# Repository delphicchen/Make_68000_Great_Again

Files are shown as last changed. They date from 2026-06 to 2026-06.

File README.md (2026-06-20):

# 68k nano — PGA-68 / 4-layer edition

A hardware fork of **[68k nano](https://github.com/74hc595/68k-nano)**, Matt
Sarnoff's minimal single-board Motorola 68000 computer, **adapted to use a
PGA-68 packaged CPU (MC68HC000RC) instead of the original DIP-64**, and
re-laid-out on a **4-layer** board.

The electrical design — the memory map, glue logic, RAM/ROM/UART, the ROM
firmware, and all software — is Matt Sarnoff's original work, used here under the
BSD-3-Clause license (see below). **This fork only changes the CPU package and the
physical board layout; the schematic netlist is unchanged.**

> ⚠️ This is an unofficial derivative and is **not affiliated with, nor endorsed
> by, the original author.**

---

## What this fork changes

- **CPU package: DIP-64 → PGA-68.** New footprint `PadRows:MC68HC000_PGA68` whose
  **pad numbers equal the DIP-64 pin numbers**, so the existing `CPU_NXP_68000`
  schematic symbol and the entire netlist are reused unchanged.
- **4-layer stackup.** A PGA's inner pins cannot "escape" on two layers, so the
  board is now: `F.Cu` / `B.Cu` signal, **`In1.Cu` = GND plane, `In2.Cu` = VCC
  plane**.
- **Re-laid-out and re-routed.** Main components repositioned to clear the PGA;
  the board is fully auto-routed from the command line (FreeRouting headless) with
  a small custom maze router closing any nets FreeRouting leaves. Result:
  **0 unconnected, 0 copper/clearance DRC violations.**
- **Verified pin-by-pin.** Every pad was checked two ways — (1) it carries the
  same net as the original DIP board, and (2) its physical grid location matches
  the Motorola M68000 datasheet PGA pinout (Fig 11-2). See `PGA68/verify_pins.py`.

## This fork's additions — see [`PGA68/`](PGA68/)

> The notes in `PGA68/` are written in 中文 (Traditional Chinese).

| File | What it is |
|---|---|
| `pin_mapping_DIP64_to_PGA68.md` | DIP-64 ↔ PGA-68 pin map + datasheet bottom-view chart |
| `verify_pins.py` | Pin-by-pin verification (netlist + datasheet placement) |
| `4層佈線完成報告.md` | Routing completion report (layers, DRC, file list) |
| `convert_4layer.py`, `import_ses_4l.py`, `add_pours.py`, `maze_route_6.py`, `rebuild_pga_pcb.py` | The conversion / routing scripts |
| `顯示器擴充指南.md` | Adding a display (ESP32/FabGL serial terminal, or a bus video card) |
| `設計隨筆.md` | Design notes (compute-power irony, "smart peripheral" philosophy) |

Board files:

- **`68000sbc.kicad_pcb`** — the board, opens by default with the
  `68000sbc.kicad_pro` project. 4-layer layout with components re-placed and the
  board fully re-routed; DRC-clean (0 unconnected, 0 copper/clearance violations).
- `68000sbc_v1.kicad_pcb` — the earlier layout, kept for reference (open directly
  in the PCB editor).
- `68000sbc.sch` (schematic, shared), and the footprint
  `PadRows.pretty/MC68HC000_PGA68.kicad_mod`.

A reusable, board-agnostic version of the headless routing workflow also exists as
a Claude Code skill (`kicad-autoroute`); it is not part of this repo.

---

## The original design & full documentation

**Everything about how the computer actually works** — features, the memory map,
the bill of materials, how to build it, and the ROM firmware (boot process,
interactive command shell, serial loader, debugger, system-call API) — is from the
original project and is preserved unchanged here as
**[`README.original.md`](README.original.md)** (and `API.md`, `bom.txt`, `code/`).

- **Original project:** *68k nano* by **Matt Sarnoff** — <https://github.com/74hc595/68k-nano>
- <https://msarnoff.org> · [@txsector](https://twitter.com/txsector)

If you want to actually build and run this, **read `README.original.md` first** —
the part counts, firmware, and usage are all there. This PGA-68 board needs the
same BOM, just with a PGA-socketed `MC68HC000RC` in place of the DIP-64 CPU. A full
English purchasing list for *this* board — generated from the actual footprints,
with sockets, the 4-layer PCB spec, and build notes — is in **[`BOM.md`](BOM.md)**.

## License

BSD 3-Clause License — Copyright (c) 2020 Matt Sarnoff. See [`LICENSE`](LICENSE).

The PGA-68 conversion work added in this fork (the footprint, the `PGA68/` scripts
and notes, and the board re-layout) is contributed under the same BSD-3-Clause
terms.

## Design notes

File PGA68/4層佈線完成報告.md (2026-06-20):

# 68k-nano PGA-68 — 4 層板佈線完成報告（2026-06-14）

---

## 更新（2026-06-20）：目前定案檔為 v2,腳位已對 datasheet 逐格核實 ✅

**目前 active／定案檔 = `68k-nano/68000sbc.kicad_pcb`（v2,使用者重新擺位後重佈線版）。**
本報告下方原始數據為 v1;v2 走線更精簡。板外框 **127.0 × 97.25 mm**。

| 項目 | v1（舊） | v2（目前 active） |
|---|---|---|
| 走線段 | 2540 | **1964** |
| via | 200 | **96** |
| 鋪銅區 | 4 | 4 |
| 層數 | 4 | 4（F 信號／In1 GND／In2 VCC／B 信號）|

### 腳位映射完整驗證鏈（每段獨立核過,無斷點）
1. **datasheet Fig 11-2（底視圖）→ 對照表 ASCII grid**：10×10 逐格相符,4 個 NC（A1／J4／K1／K10）位置一致
2. **對照表 → footprint pad (x,y)**：68/68 pad 全數手動核對;底視圖→頂視圖**左右鏡像**方向正確（col1→+x、rowA→+y,pin-1 A1 落在 (11.43, 11.43)）
3. **footprint pad 號 = DIP 腳號 → 原理圖網路**：相容 `CPU_NXP_68000` 符號
4. **DIP 腳號 → 信號**：標準 68000 DIP-64 腳位

→ 結論：真實 **MC68HC000RC** 晶片插入後,每根針都落在帶有正確網路的孔位。網表與原始 DIP 板逐點等價。

### v2 DRC（kicad-cli 9.0.2,2026-06-20）
- **0 未連接焊盤、0 短路、0 間距違規、0 footprint 錯誤**
- 14 條非電氣違規（**不阻斷打板**）：
  - `courtyards_overlap` ×10：去耦電容／排阻貼著各自 IC 擺（外觀／機械,通常可接受）
  - `solder_mask_bridge` ×4：連接器 **J1** 相鄰不同網路焊盤的綠漆橋寬 < 0.25mm（組裝時注意吃錫橋,非銅短路）

### 採購清單
- 英文版見 [`../BOM.md`](../BOM.md)（repo 內,依 v2 實際 footprint 產生,含驗證摘要）

---

## 結論：佈線 100% 完成 ✅

DIP-64 主板成功改造為 **PGA-68 / 4 層板**並完成全部佈線：
- **未連接：0**（全部網路接通）
- **電氣/銅箔 DRC 違規：0**（無短路、無間距違規、無懸空走線、無孔距違規）
- 走線 2540 段、via 200 個、4 個鋪銅區
- 剩 184 條 DRC 為外觀/程式庫類（文字大小、絲印、footprint 與庫差異），與原始上游板同類，**非打板阻斷項**

## 流程

1. **DIP-64 → PGA-68**：footprint pad 號 = DIP 腳號（相容原符號），中心 (63.5, 45.72)
2. **避讓搬移**：X1/X2 振盪器 → (72.39, 76.2)；J5/J6 排針 → 頂邊條帶 (y 34.29)；板頂邊上移 6.4mm
3. **改 4 層板**（PGA 內圈腳在 2 層板無法逃線）：
   - F.Cu(信號) / In1.Cu(GND 實心平面) / In2.Cu(VCC 實心平面) / B.Cu(信號)
4. **FreeRouting 自動佈線**（4 層全信號層）：137 條 → 完成 119（87%）
5. **加內層電源平面**：In1=GND、In2=VCC，pad 連接設 FULL（實心）
6. **自製迷宮繞線器**接完剩下 6 條（FreeRouting 卡住的跨板長走線）：
   - 0.1mm 格、Lee/Dijkstra、4 鄰（直角）、via 用獨立放置網格做間距檢查
   - `/A22 /~RDU /A5 /A13 /A1 /A4` 全部接通，DRC 零電氣違規

## 層疊（送嘉立創需指定 4 層）

| 層 | 用途 |
|----|---|
| F.Cu（頂） | 信號 |
| In1.Cu | GND 實心平面 |
| In2.Cu | VCC 實心平面 |
| B.Cu（底） | 信號 |

## 檔案

- `68k-nano/68000sbc.kicad_pcb` — **最終檔（4 層、100% 佈線、DRC 電氣零違規）**
- `68k-nano/68000sbc.kicad_pcb.backup_fully_routed` — 完成版備份
- `68k-nano/68000sbc.kicad_pcb.backup_before_maze` — 接最後 6 條前（FreeRouting 完成 119 條）
- `68k-nano/68000sbc.kicad_pcb.backup_4layer_autoroute` / `backup_2layer_routed` / `backup_original`
- 腳本：`convert_4layer.py`、`import_ses_4l.py`、`add_pours.py`、`maze_route_6.py`、`rebuild_pga_pcb.py`

## 送廠前建議（選做，非必要）

1. KiCad 開 `68000sbc.pro`，按 B 重算鋪銅，跑一次 GUI DRC 複核
2. 外觀類違規想清可調參考標號文字大小／挪動重疊絲印——不影響電氣與打板
3. 確認鑽孔/線寬符合嘉立創 4 層製程（目前線寬 0.254mm、via 0.69/0.33mm，皆在標準製程內）
4. 出 Gerber + 鑽孔檔 → 嘉立創下單（指定 4 層）

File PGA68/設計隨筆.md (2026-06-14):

# 設計隨筆：算力反差與「智慧週邊」哲學

## 一個有趣的反差

當我們用路線 A（ESP32/FabGL 串列終端機）給這台 68000 加螢幕時，會發現一件很妙的事：
**拿來「當螢幕」的那顆 MCU，本身就是一台比它服務的主機強好幾十倍的電腦。**

| | 68HC000 @ 12MHz | RP2040 | ESP32 |
|---|---|---|---|
| 核心 | 1 × 16/32-bit | 2 × Cortex-M0+ @133MHz | 2 × LX6 @240MHz |
| 整數吞吐 | ~1.5 MIPS | ~250 DMIPS | ~600 DMIPS + FPU |
| 晶片成本 | 古董/收藏價 | ~$1 | ~$2 |
| 無線 | 無 | 無 | WiFi/BT |

單看算力，一顆 1 美元的 Pico 大概是這顆 68000 的**近百倍**。
唯一一項 68k 不輸的是外接 RAM 有 1MB（比 Pico 內建 264KB 大），但那是掛在慢速匯流排上的。

## 這不是特例，是常態

現在你用的鍵盤、滑鼠、SSD 控制器、甚至 USB-C 充電頭裡的 MCU，
算力都電爆 1980 年代的整台電腦。「週邊比主機強」早就是普遍現象。

## 而且當年就這樣了

- **Commodore 1541 軟碟機**裡塞了一顆自己的 6502，跟主機 C64 的 CPU 同款——
  磁碟機跟電腦本體一樣強。
- **Amiga** 靠 Agnus / Denise / Paula 三顆自訂晶片幫 68000 扛圖形與音效。

「聰明週邊分擔笨主機」是老把戲。所以**路線 A 其實正中歷史的紅心**：
讓便宜的現代 MCU 當「智慧型 I/O 協處理器」扛掉影像 / 鍵盤 / 儲存 / 網路這些雜事，
68000 專心當那顆你**真正在寫、而且看得懂全貌**的核心。

## 那為什麼還要玩 68000？

它的價值從來不是算力，是**可理解性（comprehensibility）**：

- **看得懂全貌**：整張板子每一條線、每個 bus cycle、整個記憶體圖，都能裝進腦袋。
  bare-metal 組語直接戳硬體。現代 SoC 是幾十億顆電晶體的黑盒子，你永遠摸不透。
- **確定性（determinism）**：每條指令吃幾個 clock 都是固定的，可以 cycle-exact 地推算時序。
  現代 superscalar / cached / out-of-order CPU 的執行時間無法預測。
- **匯流排可駭性（hackability）**：你可以把真實硬體掛上 68000 的匯流排（這正是路線 B 的本質）。
  ESP32 的內部匯流排你碰不到。
- **血統**：初代 Macintosh、Amiga、Atari ST、Sega Genesis、早期 Sun 工作站、
  一堆大型電玩機台，全是這顆。慢歸慢，夠經典。

## 一句話

> 它跑得慢，但它是**你的**。
>
> 把現代 MCU 當智慧週邊、68000 當看得懂的核心——這不是妥協，
> 而是這類自製復古電腦最對味的玩法。

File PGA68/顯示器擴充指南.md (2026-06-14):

# 68k-nano 加顯示器指南（ESP32 終端機 + 匯流排顯示卡）

68k-nano 本身**沒有顯示功能**，主控台是 16550 UART → J2「5V FTDI SERIAL」。
要接螢幕有兩條路線：

- **路線 A — ESP32/Pico 當「串列終端機」**：不改板、不改 68000 韌體，最快。（建議先做這個）
- **路線 B — 在 68000 匯流排上加記憶體映射顯示卡**：CPU 直接畫面，但工程量大。（先記錄，未來想做圖形/遊戲再用）

---

## 路線 A：ESP32 + FabGL 串列終端機（推薦）

### 原理
ESP32 跑終端機模擬器（FabGL），把 68000 從 UART 送出的字元畫到 VGA 螢幕，
再把 PS/2 鍵盤打的字送回 UART。對 68000 來說它仍然只是在跟一個串列終端機講話，
**板子和韌體完全不用動**。

### 硬體
| 項目 | 建議 |
|---|---|
| 主板 | **TTGO VGA32 / FabGL VGA32**（ESP32 + VGA + 2×PS/2 + audio，為 FabGL 量身做，最省事）|
| 或 | 一般 **classic ESP32**（ESP32-WROOM）自己拉 VGA 電阻 DAC |
| 螢幕 | VGA 顯示器 |
| 鍵盤 | PS/2 鍵盤（或 USB 鍵盤 + PS/2 轉接，需支援 PS/2 模式）|

> ⚠️ FabGL 的 VGA 輸出**只支援初代 ESP32**（用它的 I2S/DAC），
> **不要用 ESP32-S2/S3/C3**。買 VGA32 板最保險。

### 接線（J2 ↔ ESP32）

J2 是 6-pin「5V FTDI SERIAL」，關鍵四隻腳：**TXD（板子送出）、RXD（板子接收）、5V、GND**。
（請以板上絲印為準確認腳序。）

```
68k-nano J2                         ESP32 (3.3V!)
-----------                         -------------
GND  ───────────────────────────── GND
TXD (5V out) ──[ 2kΩ ]──┬───────── RX (UART2 RX)   ← 分壓降到 ~3.3V
                        │
                     [ 1kΩ ]
                        │
                       GND
RXD (5V in)  ─────────────────────  TX (UART2 TX)   ← 3.3V 直接接通常 OK
5V           ─────────────────────  5V / VIN        ← 供電給 ESP32（走板上穩壓）
```

**電平轉換重點（務必）：**
- **68000 TXD 是 5V**，ESP32 腳位只耐 3.3V → 中間要**分壓**（如 2kΩ 上 + 1kΩ 下，
  5V×(1k/(2k+1k))≈… 用 1.8k/3.3k 之類得到 ~3.3V 亦可），或用現成 level shifter。直接接會傷 ESP32。
- ESP32 TXD 3.3V → 16550 RXD：3.3V 對 5V TTL 算高電位，通常可直接接；不穩再加轉換。
- 用 J2 的 5V 餵 ESP32 的 **5V/VIN** 腳（板上有穩壓），別接 3.3V 腳。

### Baud rate
要和 68000 韌體設定的鮑率一致。看 `code/baudrate.py` 與 ROM 韌體設定
（常見 115200 8N1）。FabGL 終端機這端設成同樣值。

### 韌體（Arduino IDE + FabGL）

從 FabGL 內建範例 **`AnsiTerminal`** 改最快。最小骨架（API/腳位以你的 FabGL 版本與板子為準）：

```cpp
#include "fabgl.h"

fabgl::VGAController  DisplayController;
fabgl::PS2Controller  PS2Controller;
fabgl::Terminal       Terminal;

void setup() {
  PS2Controller.begin(PS2Preset::KeyboardPort0, KbdMode::GenerateVirtualKeys);
  DisplayController.begin();
  DisplayController.setResolution(VGA_640x480_60Hz);   // 80x30 字

  Terminal.begin(&DisplayController);
  Terminal.enableCursor(true);

  // 連到接 68000 的 UART2；baud 要對上韌體，rxPin/txPin 依接線
  Terminal.connectSerialPort(115200, true, /*rxPin=*/34, /*txPin=*/2);
  Terminal.write("\e[2J68k-nano terminal ready\r\n");
}

void loop() {
  Terminal.pollSerialPort();
}
```
> VGA32 板的 `AnsiTerminal` 範例已內建正確 VGA/PS2/UART 腳位，直接燒進去多半即用。

### 上電步驟
1. ESP32 燒好終端機韌體，接 VGA 螢幕 + PS/2 鍵盤。
2. J2 ↔ ESP32 按上表接好（含分壓）。
3. 68000 板上電（ROM 已燒韌體）→ 開機訊息應出現在 VGA 螢幕，鍵盤可輸入。

**工作量：約一個週末。68000 板原封不動。**

---

## 路線 B：68000 匯流排記憶體映射顯示卡（未來參考）

讓 68000 直接寫顯示記憶體 / 顯示控制器暫存器。真正的「顯示卡」，速度快、能做圖形與遊戲，
但難度高很多。

### 三個必須先解決的硬問題

1. **板子沒有拉出完整擴充匯流排**
   對外只有 IDE（J4）、串列（J2）、RTC SPI（J3）。要接顯示卡得從晶片腳飛線拉
   D0–D15、A1–A23、`/AS`、`R/W`、`/UDS`、`/LDS`、CLK、VCC/GND——
   **建議直接改板加一條擴充匯流排排針**，不要在現板上飛一堆線。

2. **`~DTACK` 被硬接到 GND（零等待週期）**
   現設計每個匯流排週期都立即結束（12MHz 下一個週期 ≈ 333ns）。
   新顯示裝置**必須能跟上全速週期**；若用較慢的顯示晶片需要等待狀態，
   就得**切斷 DTACK→GND**，改成由位址解碼 + 裝置 ready 來產生 `~DTACK`。這是最大的改動點。

3. **部分解碼（partial decode）**
   現有：`/ROMSEL=/A23`、`/RAMSEL=A22`、`/UARTSEL=A23·/A22·A21`、`/CARDSEL=A20`。
   記憶體圖中 **`$800000–$8FFFFF` 是 open bus**（A23=1,A22=0,A21=0,A20=0，現有 select 全不命中），
   正好留給擴充。要用它得**自己加一個片選**：
   ```
   /VIDSEL = A23 · /A22 · /A21 · /A20 · /AS   (active low)
   ```
   用一顆 74HC138/GAL/ATF16V8，或 74HC139 的備用半邊產生。

### 匯流排介面要點
- 68000 是 16-bit 資料匯流排，靠 `/UDS`、`/LDS` 做高/低位元組存取——
  8-bit 顯示晶片要像 ROM/RAM 那樣接到 D0–D7 或 D8–D15 並用對應的 DS。
- 顯示裝置未被選到時資料線要 **tri-state**（用 `/VIDSEL` 控 `/CS`/`/OE`）。
- 讀寫方向用 `R/W`（+ `/UDS`/`/LDS`）轉成裝置的 `/RD`、`/WR`。

### 顯示硬體選項
| 方案 | 說明 | 難度 |
|---|---|---|
| **VDP（TMS9918A / V9938 / V9958）** | 自帶 VRAM，匯流排介面簡單（資料線 + mode + CS + RD/WR），輸出 RGB/復合。經典、資料多 | 中（注意存取時序，可能要 DTACK）|
| **並列介面 LCD 控制器**（RA8875 / SSD1963 / ILI9341 並列模式）| 接 TFT/LCD，暫存器映射到匯流排 | 中 |
| **RP2040 / ESP32 當「匯流排週邊」** | 把 MCU 映射到 `$800000`，68000 寫字元/指令，MCU 負責 HDMI/VGA 時序 | 中（不用 FPGA，靈活）|
| **CPLD/FPGA framebuffer + SRAM** | 自製 VGA/HDMI framebuffer，最自由 | 高 |

### 韌體（68000 端）
- 寫驅動：初始化顯示晶片、`putchar`/console 常式；可把韌體主控台從 UART 改導向到顯示。
- 若做 framebuffer，提供畫點/畫字/捲動常式。

### 路線 B 建議
- 想最快又「真顯示卡」感：**VDP（V9958）** 或 **RP2040-當週邊**，
  做成一張小擴充板，加 `/VIDSEL` 解碼，必要時改 DTACK。
- **務必改板拉一條標準擴充匯流排排針**（含 D0–D15、A1–A23、`/AS`、`R/W`、`/UDS`、`/LDS`、
  CLK、`/DTACK`、IRQ、VCC/GND），之後要加任何週邊都方便。

---

## 一句話總結
- **只想看到畫面、能打字** → 路線 A，ESP32/FabGL 當串列終端機，最快、不動板。
- **要 CPU 直接控制圖形/遊戲** → 路線 B，改板加擴充匯流排 + 顯示卡（VDP 或 MCU 當週邊最實際），
  並注意 `~DTACK` 目前接地這件事。

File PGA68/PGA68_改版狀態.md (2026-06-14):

# 68k-nano PGA-68 改版狀態（2026-06-12）

## 已完成

| 項目 | 內容 |
|---|---|
| Footprint | `PadRows.pretty/MC68HC000_PGA68.kicad_mod`（pad 號 = DIP-64 pin 號，直接相容原符號）|
| 腳位對照 | `pin_mapping_DIP64_to_PGA68.md`（含底視圖示意圖）|
| 原理圖 | U3 → `PadRows:MC68HC000_PGA68`，value → `MC68HC000RC10` |
| PCB U3 | DIP-64 換成 PGA-68，中心 **(63.5, 45.72)**（右移一格避開左上固定孔）|
| X1/X2 振盪器 | 原位置撞 PGA 左下角 → 移到 **(72.39, 76.2)**，靠近 CLK pad E1 |
| J5/J6 匯流排 pad 排 | 左端撞 PGA 右側 → 移到新頂邊條帶 **(pads x 78.74–139.7, y 34.29)** |
| 舊走線清除 | 194 segments + 43 vias（PGA 區、舊振盪器區、舊 DIP 區 U3 網路）|
| 板邊 | 頂邊上移 6.445mm（y 38.735 → 32.29），GND 鋪銅輪廓同步擴展 |
| 舊 zone 填充 | 已清除 16 塊 stale `filled_polygon`（會讓 KiCad 9 DRC 卡死；開檔後按 B 重算）|

## DRC 驗證結果（kicad-cli 9.0.2）

- **短路：0**、銅箔/邊緣衝突：無新增
- 未連接項目：171（= 待佈線的 ratsnest，預期中）
- track/via_dangling 111：清走線留下的殘端，GUI 裡用
  「Edit → Cleanup Tracks & Vias → 刪除懸空走線」一鍵清掉
- 其餘（text_height、silk、lib_mismatch 等）為原板既有問題

## 重現方式

```bash
cd 68k-nano
cp 68000sbc.kicad_pcb.backup_original 68000sbc.kicad_pcb
python3 ../rebuild_pga_pcb.py
```

## 待完成（KiCad GUI）

1. 開 `68000sbc.pro`（KiCad 9 會提示格式升級，正常）
2. 按 **B** 重算鋪銅
3. Cleanup Tracks & Vias 清除懸空殘端
4. 依 ratsnest 佈線：58 個 PGA 信號 pad、X1/X2、J5/J6 左段
   （VCC/GND 多數會被 GND pour / 電源走線吃掉）
5. C2（振盪器去耦）建議移到新振盪器旁
6. DRC 全過 → 出 Gerber → 嘉立創

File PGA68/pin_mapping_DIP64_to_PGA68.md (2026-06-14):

# MC68000 / MC68HC000 — DIP-64 對 PGA-68 腳位對照表

資料來源：Motorola M68000 User's Manual (9th Ed.), Figure 11-1 & 11-2

## 封裝說明

| 封裝 | 型號後綴 | 腳位數 | 說明 |
|---|---|---|---|
| DIP-64 | P, R | 64 | 雙排直插，2.54mm 間距，900mil 寬 |
| PGA-68 | RC | 68 | 陣列插針，2.54mm 間距，10×10 格（缺4角） |

**你的零件**：MC68HC000**RC**10 → PGA-68 封裝

## 腳位對照表

PGA-68 方向說明（底視圖，與資料手冊 Figure 11-2 一致）：
- 行（Row）：A（下）→ K（上），跳過 I
- 列（Col）：1（左）→ 10（右）
- PCB 上放置時：左右鏡像（因為翻面）

| 信號 | DIP-64 | PGA-68 | 信號說明 |
|---|---|---|---|
| D4 | 1 | A5 | 資料匯流排 bit 4 |
| D3 | 2 | B5 | 資料匯流排 bit 3 |
| D2 | 3 | A4 | 資料匯流排 bit 2 |
| D1 | 4 | A3 | 資料匯流排 bit 1 |
| D0 | 5 | B4 | 資料匯流排 bit 0 |
| ~AS | 6 | A2 | 位址選通（低有效） |
| ~UDS | 7 | B3 | 上位元組選通（低有效） |
| ~LDS | 8 | B2 | 下位元組選通（低有效） |
| R/~W | 9 | C3 | 讀/寫控制 |
| ~DTACK | 10 | B1 | 資料傳輸確認（低有效） |
| ~BG | 11 | C2 | 匯流排授予（低有效） |
| ~BGACK | 12 | C1 | 匯流排授予確認（低有效） |
| ~BR | 13 | D1 | 匯流排請求（低有效） |
| VCC | 14 | D2 | 電源 +5V |
| CLK | 15 | E1 | 系統時脈輸入 |
| GND | 16 | E2 | 接地 |
| ~HALT | 17 | F1 | 暫停（雙向，低有效） |
| ~RESET | 18 | F2 | 重置（雙向，低有效） |
| ~VMA | 19 | G1 | 有效記憶體位址（低有效） |
| E | 20 | H1 | E 時脈（M6800 週邊相容） |
| ~VPA | 21 | G2 | 有效週邊位址（低有效） |
| ~BERR | 22 | J1 | 匯流排錯誤（低有效） |
| IPL2 | 23 | H2 | 中斷優先級 bit 2 |
| IPL1 | 24 | H3 | 中斷優先級 bit 1 |
| IPL0 | 25 | J2 | 中斷優先級 bit 0 |
| FC2 | 26 | K2 | 功能碼 bit 2 |
| FC1 | 27 | J3 | 功能碼 bit 1 |
| FC0 | 28 | K3 | 功能碼 bit 0 |
| A1 | 29 | K4 | 位址匯流排 bit 1 |
| A2 | 30 | J5 | 位址匯流排 bit 2 |
| A3 | 31 | K5 | 位址匯流排 bit 3 |
| A4 | 32 | K6 | 位址匯流排 bit 4 |
| A5 | 33 | J6 | 位址匯流排 bit 5 |
| A6 | 34 | K7 | 位址匯流排 bit 6 |
| A7 | 35 | K8 | 位址匯流排 bit 7 |
| A8 | 36 | J7 | 位址匯流排 bit 8 |
| A9 | 37 | K9 | 位址匯流排 bit 9 |
| A10 | 38 | J8 | 位址匯流排 bit 10 |
| A11 | 39 | J9 | 位址匯流排 bit 11 |
| A12 | 40 | H9 | 位址匯流排 bit 12 |
| A13 | 41 | H8 | 位址匯流排 bit 13 |
| A14 | 42 | J10 | 位址匯流排 bit 14 |
| A15 | 43 | G9 | 位址匯流排 bit 15 |
| A16 | 44 | H10 | 位址匯流排 bit 16 |
| A17 | 45 | G10 | 位址匯流排 bit 17 |
| A18 | 46 | F9 | 位址匯流排 bit 18 |
| A19 | 47 | F10 | 位址匯流排 bit 19 |
| A20 | 48 | E10 | 位址匯流排 bit 20 |
| VCC | 49 | E9 | 電源 +5V |
| A21 | 50 | D10 | 位址匯流排 bit 21 |
| A22 | 51 | C10 | 位址匯流排 bit 22 |
| A23 | 52 | C9 | 位址匯流排 bit 23 |
| GND | 53 | D9 | 接地 |
| D15 | 54 | B10 | 資料匯流排 bit 15 |
| D14 | 55 | B9 | 資料匯流排 bit 14 |
| D13 | 56 | C8 | 資料匯流排 bit 13 |
| D12 | 57 | A10 | 資料匯流排 bit 12 |
| D11 | 58 | B8 | 資料匯流排 bit 11 |
| D10 | 59 | A9 | 資料匯流排 bit 10 |
| D9 | 60 | B7 | 資料匯流排 bit 9 |
| D8 | 61 | A8 | 資料匯流排 bit 8 |
| D7 | 62 | A7 | 資料匯流排 bit 7 |
| D6 | 63 | B6 | 資料匯流排 bit 6 |
| D5 | 64 | A6 | 資料匯流排 bit 5 |
| NC | — | A1 | 無連接（PGA 額外腳） |
| NC | — | J4 | 無連接（PGA 額外腳） |
| NC | — | K1 | 無連接（PGA 額外腳） |
| NC | — | K10 | 無連接（PGA 額外腳） |

## PGA-68 格局示意圖（底視圖，與 datasheet Figure 11-2 相同）

```
     1    2    3    4    5    6    7    8    9   10
K   NC   FC2  FC0  A1   A3   A4   A6   A7   A9   NC
J  BERR IPL0  FC1  NC   A2   A5   A8   A10  A11  A14
H    E   IPL2 IPL1 ·    ·    ·    ·    A13  A12  A16
G  ~VMA ~VPA  ·    ·    ·    ·    ·    ·    A15  A17
F  ~HALT ~RST ·    ·    ·    ·    ·    ·    A18  A19
E   CLK  GND  ·    ·    ·    ·    ·    ·    VCC  A20
D   ~BR  VCC  ·    ·    ·    ·    ·    ·    GND  A21
C  ~BGK  ~BG  R/W  ·    ·    ·    ·    D13  A23  A22
B  ~DTK ~LDS ~UDS  D0   D3   D6   D9   D11  D14  D15
A   NC   ~AS  D1   D2   D4   D5   D7   D8   D10  D12
```
（· = 無接腳，中空區域）

## Footprint 設計說明

`MC68HC000_PGA68.kicad_mod` 中的 **pad 號碼 = DIP-64 pin 號碼**，
讓此 footprint 可直接與現有使用 DIP-64 腳位編號的符號相容。

物理位置對應：PCB 上從正面（top view）看，是底視圖的左右鏡像。

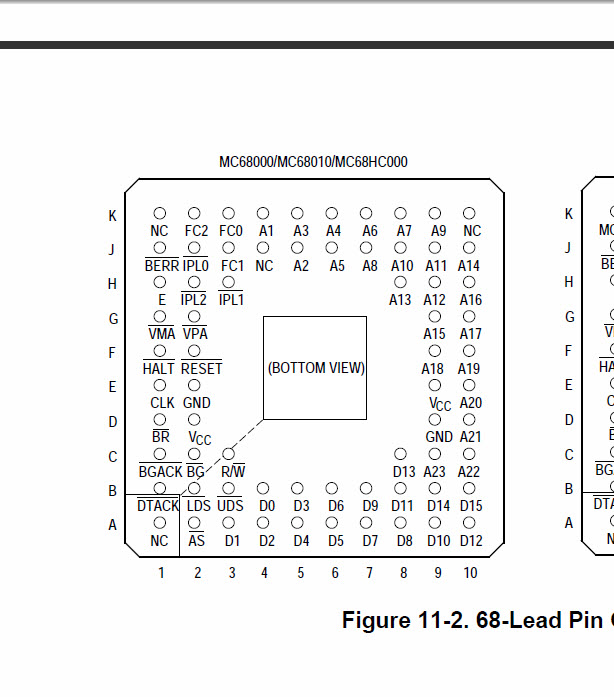
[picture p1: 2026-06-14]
PGA68/68000-PGA.jpg

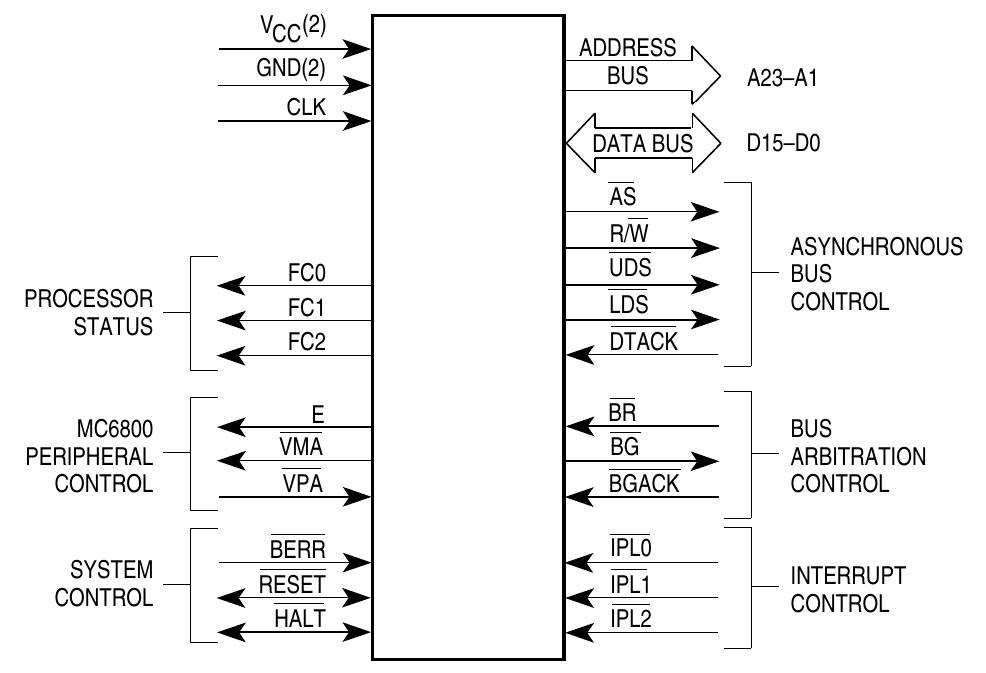
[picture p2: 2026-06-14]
PGA68/68000-DIP.png

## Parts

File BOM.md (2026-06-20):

# Bill of Materials — 68k nano (PGA-68 / 4-layer edition)

Generated from the actual footprints in the current board **`68000sbc.kicad_pcb`**
(the re-placed, re-routed v2 layout). Board: **4-layer, 127.0 × 97.25 mm**, all
parts **through-hole (THT)** — hand-solderable.

> This BOM supplements the original `bom.txt` / `README.original.md`. The
> **electrical design is unchanged** from Matt Sarnoff's *68k nano*; only the CPU
> package (DIP-64 → PGA-68) and the board layout differ. For *how the computer
> works and how to build it*, read **`README.original.md`** first.

Legend — **Qty** = number on the board · **SKU** = reference part numbers from the
original BOM (Jameco / Mouser), where available.

---

## A. Active devices (ICs)

| Ref | Part | Package | Qty | SKU | Notes |
|-----|---|---|:---:|-----|---|
| **U3** | **MC68HC000RC10** CPU | **PGA-68** | 1 | — | **You supply this** — it is the whole reason for the fork |
| U1 | 74HC139 dual 2-to-4 decoder | DIP-16 | 1 | | Address decode |
| U2 | 74HC14 hex inverting Schmitt trigger | DIP-14 | 1 | | Reset / signal conditioning |
| U4, U6 | AS6C4008-55PCN SRAM 512K×8 | DIP-32 (600 mil) | 2 | Jameco 242448 / Mouser 913-AS6C4008-55PCN | 1 MB total |
| U5, U7 | AT28C256 EEPROM 32K×8 | DIP-28 (600 mil) | 2 | Jameco 74843 / Mouser 556-AT28C25615PU | Firmware ROM |
| U8 | TL16C550(C) UART | DIP-40 (600 mil) | 1 | Jameco 288809 | Serial port |

## B. Oscillator (populate ONE)

| Ref | Part | Package | Qty | Notes |
|-----|---|---|:---:|---|
| X1 **or** X2 | Full-can crystal oscillator | DIP-14 (X1) **or** DIP-8 (X2) | **1** | X1 and X2 are **two alternative footprints for the same clock** (same CPUCLK net) — fit only one |

> ⚠️ **Frequency:** the schematic marks **12 MHz**, but U3 is an **RC10 (rated
> 10 MHz)**. 12 MHz is ~20 % overclock. To stay in spec, buy an **8 MHz or 10 MHz**
> oscillator. 12 MHz often works on HCMOS parts but is not guaranteed.

## C. Passives

| Ref | Part | Package / rating | Qty | Notes |
|-----|---|---|:---:|---|
| C1–C10 | 0.1 µF ceramic | THT, 5.0 mm pitch | 10 | Per-IC decoupling |
| C11, C12 | 10 µF electrolytic, ≥16 V | radial D5.0 mm, 2.5 mm pitch | 2 | Power filtering |
| R1, R2 | 10 kΩ, 1/4 W | axial DIN0204 | 2 | Pull-ups |
| R3 | 1 kΩ, 1/4 W | axial DIN0204 | 1 | |
| R4–R7 | LED series resistor 330 Ω–1 kΩ | axial DIN0204 | 4 | Value per LED colour/brightness |
| RN1 | 10 kΩ bussed resistor network | **SIP-7** (common pin) | 1 | Bus pull-ups |

## D. Diodes / LEDs

| Ref | Part | Package | Qty | Notes |
|-----|---|---|:---:|---|
| D1, D2 | 1N5817 Schottky (1N4148 also works) | DO-41 / DO-35, 7.62 mm pitch | 2 | Power OR-ing |
| D3 | LED "POWER" | 5 mm | 1 | Power indicator |
| D4 | LED (activity) | 5 mm | 1 | |
| D5 | LED "CARD" | 5 mm | 1 | |
| D6 | LED "HALT" | 5 mm | 1 | |

## E. Connectors / switches / mechanical

| Ref | Part | Spec | Qty | Notes |
|-----|---|---|:---:|---|
| J1 | USB-B PCB socket (horizontal) | USB-B 1HSxx Horizontal | 1 | Jameco 2096245 |
| J2 | 1×6 right-angle header | 2.54 mm | 1 | FTDI serial |
| J3 | 1×7 header | 2.54 mm vertical | 1 | RTC (SparkFun BOB-10160) — optional |
| J4 | 2×22 header | **2.00 mm** vertical | 1 | CF / IDE interface |
| J5, J6 | 1×25 expansion pad rows | 2.54 mm (PCB pads) | 0–2 | EXPANSION — fit headers only if used |
| JP1 | 1×3 header + jumper | 2.54 mm vertical | 1 | Power select |
| SW1, SW2 | 6 mm tactile switch | THT | 2 | RESET / BTN1 |
| H1–H4 | M2.5 screw + standoff/spacer | 2.7 mm hole | 4 sets | Mounting holes |

## F. IC sockets (recommended — footprints are the "Socket" variants)

| For | Socket | Qty |
|-----|---|:---:|
| U1 | DIP-16 | 1 |
| U2 | DIP-14 | 1 |
| U4, U6 | DIP-32 (600 mil / wide) | 2 |
| U5, U7 | DIP-28 (600 mil / wide) | 2 |
| U8 | DIP-40 (600 mil / wide) | 1 |
| X1/X2 | DIP-14 or DIP-8 (optional — oscillator can be soldered) | 1 |
| **U3** | **PGA-68 socket** (specialty part, optional — solder directly if unavailable) | 1 |

> For U5/U7 (EEPROM), if you reflash often, use a **ZIF-28 socket** (Jameco 102745
> / Aries 28-526-10). A PGA-68 socket for U3 is a specialty item; soldering the CPU
> directly avoids it.

## G. The PCB itself

| Item | Spec |
|---|---|
| Layers | **4** — F.Cu signal / In1.Cu GND plane / In2.Cu VCC plane / B.Cu signal |
| Size | 127.0 × 97.25 mm |
| Trace / via | 0.254 mm trace; 0.69 / 0.33 mm via (both standard-process at JLCPCB) |
| Order | Export Gerbers + drill → fab as a **4-layer** board |

## H. Buying checklist

1. **U3 you supply** (MC68HC000RC10, PGA-68) — prerequisite of this fork.
2. **Buy only one oscillator**, and prefer **≤10 MHz** to keep the RC10 in spec
   (the design currently marks 12 MHz, which is overclocking).
3. **Sockets:** all seven DIP ICs use socket-variant footprints — buy the sockets
   too. The U3 PGA-68 socket is optional.
4. **J4 is 2.00 mm pitch** (everything else is 2.54 mm) — don't buy the wrong header.
5. **Optional:** J3 (RTC), J5/J6 (expansion headers), and a CF↔IDE adapter, as needed.
6. Peripherals mentioned by the original BOM: SparkFun DeadOn RTC BOB-10160;
   CompactFlash → 2.5" 44-pin IDE adapter.

---

## Layout verification (why this board is correct)

The DIP-64 → PGA-68 conversion was verified end-to-end:

- **Netlist identical to the original DIP board** — the PGA footprint's pad numbers
  equal the DIP-64 pin numbers, so the schematic and every net are reused unchanged.
- **Physical pin placement matches the datasheet** — all 68 pads were checked
  against the Motorola/Freescale *M68000 User's Manual* Fig 11-2 (68-lead PGA,
  bottom view); the 10×10 grid and the four NC pads (A1, J4, K1, K10) match
  exactly, with the correct bottom-view→top-view mirror. See `PGA68/verify_pins.py`
  and `PGA68/pin_mapping_DIP64_to_PGA68.md`.
- **DRC (KiCad 9):** 0 unconnected pads, 0 shorts, 0 clearance violations, 0
  footprint errors. The remaining 14 violations are non-electrical and do not block
  fabrication — courtyard overlaps (decoupling caps/resistors hugging their ICs)
  and a solder-mask web between adjacent different-net pads on connector J1.

---
*Generated 2026-06-20 from the v2 PCB (49 footprints) and `bom.txt`.*

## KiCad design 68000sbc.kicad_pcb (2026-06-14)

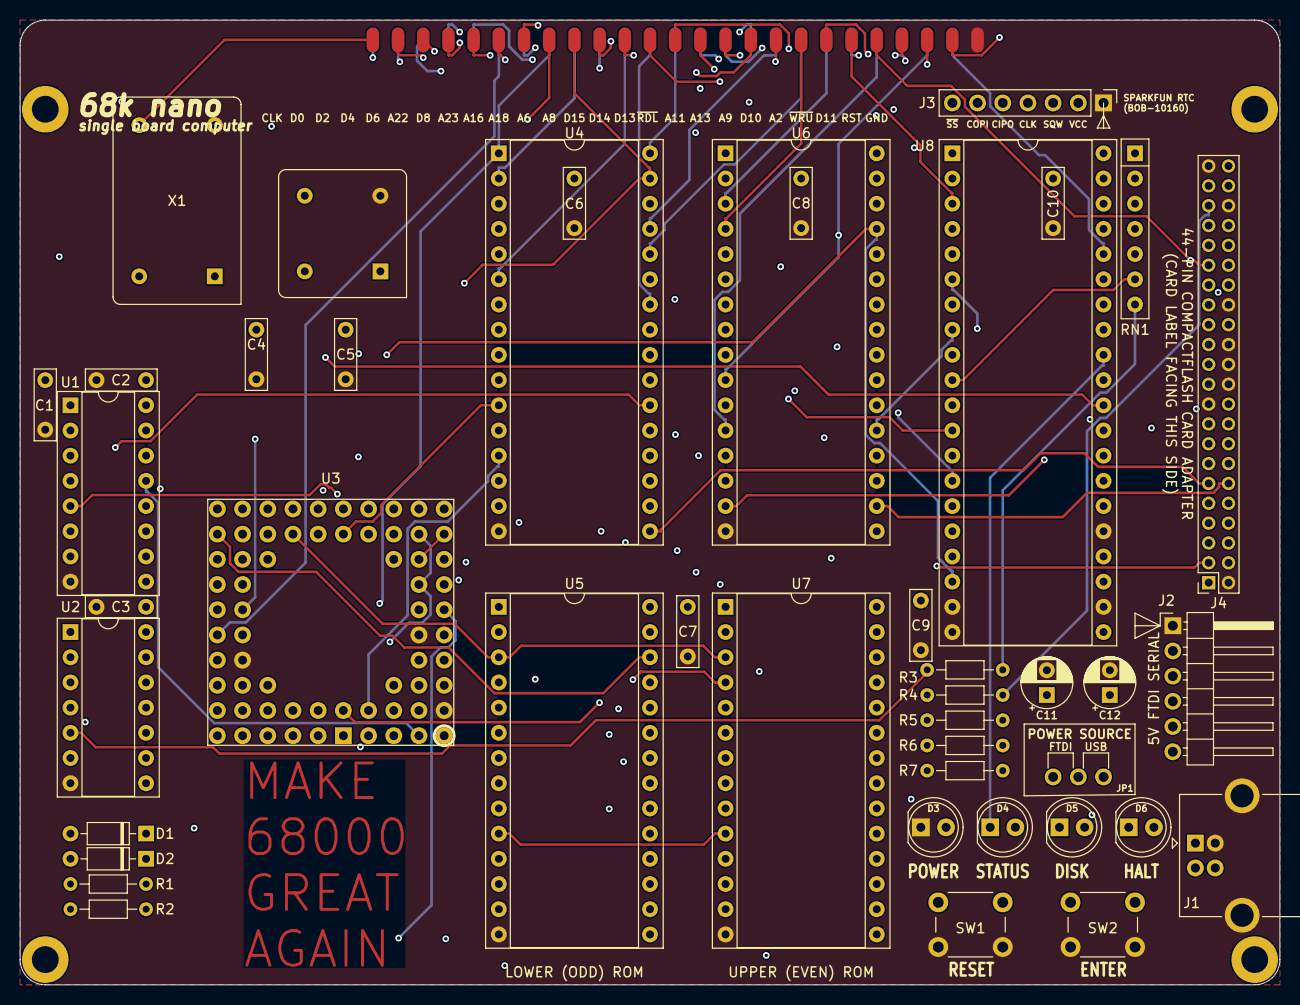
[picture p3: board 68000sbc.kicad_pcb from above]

Board: 4 copper layers, 127.0 x 97.2 mm, 49 parts (1 on the bottom side), 80 nets.

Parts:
C1, C2, C3, C4, C5, C6, C7, C8, C9, C10: 0.1uF; C_Rect_L7.0mm_W2.0mm_P5.00mm
C11, C12: 10uF; CP_Radial_D5.0mm_P2.50mm
D1, D2: 1N5817; D_DO-35_SOD27_P7.62mm_Horizontal
D3: POWER; LED_D5.0mm
D4: LED; LED_D5.0mm
D5: CARD; LED_D5.0mm
D6: HALT; LED_D5.0mm
H1, H2, H3, H4: MountingHole_2.7mm_M2.5_DIN965_Pad
J1: USB_B; USB_B_OST_USB-B1HSxx_Horizontal
J2: 5V FTDI SERIAL; PinHeader_1x06_P2.54mm_Horizontal
J3: RTC (SparkFun BOB-10160); PinHeader_1x07_P2.54mm_Vertical
J4: CFCARD/IDE; PinHeader_2x22_P2.00mm_Vertical
J5: EXPANSION (F.Cu); PadRow_1x25_P2.54mm
J6: EXPANSION (B.Cu); PadRow_1x25_P2.54mm
JP1: POWER SELECT; PinHeader_1x03_P2.54mm_Vertical
R1, R2: 10k; R_Axial_DIN0204_L3.6mm_D1.6mm_P7.62mm_Horizontal
R3: 1k; R_Axial_DIN0204_L3.6mm_D1.6mm_P7.62mm_Horizontal
R4, R5, R6, R7: 1k*; R_Axial_DIN0204_L3.6mm_D1.6mm_P7.62mm_Horizontal
RN1: 10k; R_Array_SIP7
SW1: RESET; SW_PUSH_6mm
SW2: BTN1; SW_PUSH_6mm
U1: 74HC139; DIP-16_W7.62mm_Socket
U2: 74HC14; DIP-14_W7.62mm_Socket
U3: MC68HC000RC10; MC68HC000_PGA68
U4, U6: AS6C4008-55PCN; DIP-32_W15.24mm_Socket
U5, U7: 28C256; DIP-28_W15.24mm_Socket
U8: TL16C550; DIP-40_W15.24mm_Socket
X1: 12MHz; Oscillator_DIP-14
X2: 12MHz; Oscillator_DIP-8

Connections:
/A1: J4.35, J6.21, U3.29, U4.12, U5.10, U6.12, U7.10, U8.28
/A2: J4.33, J5.21, U3.30, U4.11, U5.9, U6.11, U7.9, U8.27
/A3: J4.36, J6.23, U3.31, U4.10, U5.8, U6.10, U7.8, U8.26
/A4: J6.16, U3.32, U4.9, U5.7, U6.9, U7.7
/A5: J6.14, U3.33, U4.8, U5.6, U6.8, U7.6
/A6: J5.11, U3.34, U4.7, U5.5, U6.7, U7.5
/A7: J6.11, U3.35, U4.6, U5.4, U6.6, U7.4
/A8: J5.12, U3.36, U4.5, U5.3, U6.5, U7.3
/A9: J5.19, U3.37, U4.27, U5.25, U6.27, U7.25
/A10: J6.12, U3.38, U4.26, U5.24, U6.26, U7.24
/A11: J5.17, U3.39, U4.23, U5.21, U6.23, U7.21
/A12: J6.20, U3.40, U4.25, U5.23, U6.25, U7.23
/A13: J5.18, U3.41, U4.4, U5.2, U6.4, U7.2
/A14: J6.18, U3.42, U4.28, U5.26, U6.28, U7.26
/A15: J6.19, U3.43, U4.3, U5.1, U6.3, U7.1
/A16: J5.9, U3.44, U4.31, U6.31
/A17: J6.9, U3.45, U4.2, U6.2
/A18: J5.10, U3.46, U4.30, U6.30
/A19: J6.8, U3.47, U4.1, U6.1
/A20: J6.6, U2.11, U3.48
/A21: J6.10, U3.50, U8.12
/A22: J5.6, U2.9, U3.51, U8.14
/A23: J5.8, U3.52, U5.20, U7.20, U8.13
/CPUCLK: J5.1, U3.15, U8.16, X1.8, X2.5
/D0: J4.17, J5.2, U3.5, U4.13, U5.11
/D1: J4.15, J6.2, U3.4, U4.14, U5.12
/D2: J4.13, J5.3, U3.3, U4.15, U5.13
/D3: J4.11, J6.3, U3.2, U4.17, U5.15
/D4: J4.9, J5.4, U3.1, U4.18, U5.16
/D5: J4.7, J6.4, U3.64, U4.19, U5.17
/D6: J4.5, J5.5, U3.63, U4.20, U5.18
/D7: J4.3, J6.5, U3.62, U4.21, U5.19
/D8: J4.4, J5.7, U3.61, U6.13, U7.11, U8.1
/D9: J4.6, J6.7, U3.60, U6.14, U7.12, U8.2
/D10: J4.8, J5.20, U3.59, U6.15, U7.13, U8.3
/D11: J4.10, J5.23, U3.58, U6.17, U7.15, U8.4
/D12: J4.12, J6.15, U3.57, U6.18, U7.16, U8.5
/D13: J4.14, J5.15, U3.56, U6.19, U7.17, U8.6
/D14: J4.16, J5.14, U3.55, U6.20, U7.18, U8.7
/D15: J4.18, J5.13, U3.54, U6.21, U7.19, U8.8
/EXTIRQ: J6.24, RN1.5, U8.36
/IRQ: U2.13, U8.30
/R,~W: U1.2, U1.14, U3.9
/RESET: J5.24, U2.2, U8.35
/RTC_CIPO: J3.5, RN1.3, U8.38
/RTC_CLK: J3.4, U8.34
/RTC_COPI: J3.6, U8.33
/RTC_SQW: J3.3, RN1.4, U8.37
/RXD: J2.5, U8.11
/TXD: J2.4, RN1.6, U8.10
/~A20: J4.37, U2.10
/~A22: U2.8, U4.22, U6.22
/~AS: U1.3, U1.13, U3.6
/~BTN1: RN1.2, SW2.2, U8.39
/~CFLED: J4.39, R4.1
/~HALT: D2.2, D6.1, R1.2, U3.17
/~IRQ: U2.12, U3.21, U3.25
/~LDS: U1.1, U3.8
/~RDL: J4.25, J5.16, U1.5, U4.24, U5.22
/~RDU: J6.22, U1.11, U6.24, U7.22, U8.21
/~RESETBTN: R3.2, RN1.7, SW1.2
/~RESET: D1.2, J4.1, J6.1, R2.2, U2.1, U3.18
/~RTC_SS: J3.7, U8.31
/~UDS: U1.15, U3.7
/~WRL: J4.23, J6.17, U1.4, U4.29
/~WRU: J5.22, U1.12, U6.29, U8.18
GND: C1.2, C2.2, C3.2, C4.2, C5.2, C6.2, C7.2, C8.2, C9.2, C10.2, C11.2, C12.2, D3.1, J1.4, J1.5, J2.1, J3.1, J4.2, J4.19, J4.22, J4.24, J4.26, J4.30, J4.40, J4.43, J5.25, J6.25, SW1.1, SW2.1, U1.8, U2.7, U3.10, U3.16, U3.53, U4.16, U5.14, U6.16, U7.14, U8.19, U8.20, U8.22, U8.25, X1.7, X2.4
unnamed: C11.1, R3.1, U2.5
unnamed: D1.1, D2.1, U2.4
unnamed: D3.2, R6.1
unnamed: D4.1, U8.32
unnamed: D4.2, R5.2
unnamed: D5.1, R4.2
unnamed: D6.2, R7.1
unnamed: J1.1, JP1.3
unnamed: J2.3, JP1.1
unnamed: U2.3, U2.6
unnamed: U8.9, U8.15
unnamed: X1.1, X2.1
VCC: C1.1, C2.1, C3.1, C4.1, C5.1, C6.1, C7.1, C8.1, C9.1, C10.1, C12.1, D5.2, J3.2, J4.38, J4.41, J4.42, J6.13, JP1.2, R1.1, R2.1, R5.1, R6.2, R7.2, RN1.1, U1.16, U2.14, U3.12, U3.13, U3.14, U3.22, U3.23, U3.24, U3.49, U4.32, U5.27, U5.28, U6.32, U7.27, U7.28, U8.40, X1.14, X2.8

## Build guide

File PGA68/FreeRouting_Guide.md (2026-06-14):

# KiCad 專案重置與 FreeRouting 自動佈線指南

## 專案現況更新
專案目前已經透過 `git reset --hard` 和 `git clean -fd` 徹底重置為原始狀態。所有先前的修改（包含錯誤的佈線、懸空的走線與過孔）都已經被抹除。`68k-nano` 目錄現在處於最乾淨的初始狀態（即原本的 DIP-64 配置）。

> **備份提醒**：先前的 PGA-68 腳位對照表 (`pin_mapping_DIP64_to_PGA68.md`) 以及自訂的 PGA 封裝檔 (`PadRows.pretty`) 已經被安全地備份到上一層 `Make_68000_Great_Again` 目錄中。日後若要再次嘗試 DIP 轉 PGA，可以直接從該處取用。

---

## 如何安裝與使用 FreeRouting (Linux 環境)

由於這是一張 2 層板，且如果未來要將 68 根針腳的 PGA 封裝擠入極小的面積內，純手動佈線或是用腳本強制佈線都非常容易產生大量 DRC 錯誤（短路、走線交叉）。使用專業的拓撲自動佈線演算法是最佳解法。

以下提供兩種安裝與使用 FreeRouting 的方法（強烈推薦方法一）：

### 方法一：透過 KiCad 內建外掛管理器（最推薦 🌟）

這是最簡單、最不會出錯的方式，能無縫整合 KiCad 9 的匯出/匯入流程。

1. **開啟 KiCad 主程式**（KiCad Project Manager，不需要打開特定專案）。
2. 點擊首頁的 **「外掛程式與內容管理器 (Plugin and Content Manager)」**。
3. 在頂部的搜尋列中輸入 `Freerouting`。
4. 找到 **Freerouting** 外掛後，點擊 **[Install] (安裝)**。
5. 點擊視窗左下方的 **[Apply Pending Changes] (套用變更)** 完成安裝。
6. **如何使用**：
   - 開啟你的 PCB 編輯器 (`.kicad_pcb` 檔)。
   - 在上方工具列會出現一個新的 **Freerouting 圖示**。
   - 點擊該圖示，外掛會自動匯出電路板資料、開啟 FreeRouting 進行演算，完成後再一鍵將結果匯回 KiCad，省去所有繁瑣步驟。

### 方法二：手動下載獨立執行檔 (Standalone App)

如果你偏好將軟體獨立執行，或者外掛程式有相容性問題，可以採用此方法。

1. **安裝 Java 執行環境**：
   打開終端機，輸入以下指令確保系統有 Java：
   ```bash
   sudo apt update
   sudo apt install default-jre
   ```

2. **下載 FreeRouting 程式**：
   - 前往官方 GitHub Releases 頁面：[freerouting/freerouting](https://github.com/freerouting/freerouting/releases)
   - 下載最新版的 `freerouting-x.x.x.jar`（或是 `.deb` 安裝檔直接安裝）。

3. **啟動 FreeRouting**：
   如果你下載的是 `.jar` 檔，在終端機輸入：
   ```bash
   java -jar freerouting-x.x.x.jar
   ```

4. **手動匯出與匯入流程**：
   - **在 KiCad 中匯出**：在 PCB 編輯器中，選擇 `檔案 (File)` -> `匯出 (Export)` -> `Specctra DSN`，將目前的電路板狀態存成 `.dsn` 檔。
   - **在 FreeRouting 佈線**：打開 FreeRouting 程式，載入剛才的 `.dsn` 檔，點擊上方的自動佈線按鈕讓它跑完。
   - **儲存結果**：佈線完成後，在 FreeRouting 中選擇匯出為 `.ses` (Specctra Session) 檔。
   - **在 KiCad 中匯入**：回到 KiCad PCB 編輯器，選擇 `檔案 (File)` -> `匯入 (Import)` -> `Specctra Session`，讀入該 `.ses` 檔，佈線就會完美呈現在畫面上。

---

## 下一步建議

1. 先在目前乾淨的 **DIP-64 原始版本**上，試著用 FreeRouting 跑一次自動佈線，熟悉軟體的操作手感。
2. 熟悉後，再將備份的 PGA 封裝匯入，替換掉 DIP 封裝，並再次利用 FreeRouting 解決高密度的佈線挑戰。

祝你有個好夢！明天睡醒再繼續挑戰！

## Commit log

2026-06-14 Convert DIP-64 CPU to PGA-68 (MC68HC000RC) on a 4-layer board, fully routed
    - New footprint PadRows:MC68HC000_PGA68 (pad numbers = DIP-64 pins, so the
    existing CPU_NXP_68000 symbol works unchanged)
    - U3 swapped DIP-64 -> PGA-68; X1/X2 oscillator and J5/J6 headers relocated
    to clear the PGA; top board edge raised 6.4mm
    - Board converted to 4 layers: F.Cu/B.Cu signal, In1.Cu GND plane,
    In2.Cu VCC plane (PGA inner-pin escape needs >2 layers)
    - Routed with FreeRouting (119/137 nets) + a custom maze router for the
    final 6 spans; DRC: 0 unconnected, 0 copper/electrical violations
    - PGA68/ holds the pin map, conversion scripts, and the routing report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
    [68000sbc.kicad_pcb, 68000sbc.sch]
2026-06-14 Add PGA68/verify_pins.py — pin-by-pin conversion verification
    Checks netlist integrity (U3 pad->net vs the pre-conversion DIP board read
    from git history) and physical placement (each footprint pad's grid location
    vs the MC68000 datasheet PGA pinout, with the standard DIP-64 pinout as
    independent ground truth). Current board: 0 net diffs, 0 misplaced pads.
2026-06-14 Add PGA68/顯示器擴充指南 — display options (ESP32 serial terminal + bus video card)
    Route A: ESP32/FabGL serial VGA terminal — wiring to J2 with 5V<->3.3V level
    shifting, baud notes, Arduino/FabGL firmware skeleton; no board/firmware changes.
    Route B: memory-mapped video on the 68000 bus — using the $800000 open-bus
    window, the /VIDSEL decode to add, the ~DTACK-tied-to-GND caveat, byte-lane
    (UDS/LDS) handling, and hardware options (VDP/LCD-ctrl/RP2040-peripheral/FPGA).
2026-06-14 Add PGA68/設計隨筆 — compute-power irony & "smart peripheral" design philosophy
    Notes that the ESP32/Pico terminal MCU outpowers the 68000 host by ~100x,
    why that's the norm now (every peripheral has an MCU), historical precedent
    (1541's own 6502, Amiga custom chips), and why the 68000 is still worth it:
    comprehensibility, determinism, bus hackability, heritage.
2026-06-14 Add v2 board (re-placed, re-routed) alongside v1; README lists both
    68000sbc_v2.kicad_pcb is the newer 4-layer layout with main components
    re-placed and the board fully re-routed headless (FreeRouting), DRC-clean
    (0 unconnected, 0 copper/clearance violations; 1964 seg / 96 via). v1 kept
    for reference. README marks v2 as recommended. Ignore *.kicad_prl (local UI state).
    [68000sbc_v2.kicad_pcb]
2026-06-14 Make v2 the default board: promote v2 -> 68000sbc.kicad_pcb, v1 -> _v1
    Opening the 68000sbc.kicad_pro project now brings up the v2 layout (re-placed,
    re-routed, DRC-clean). The previous layout is preserved as 68000sbc_v1.kicad_pcb
    for reference. The two project files were identical apart from the embedded
    filename field, so the redundant 68000sbc_v2.kicad_pro is dropped and the
    canonical 68000sbc.kicad_pro is kept. README board list updated.
    [68000sbc.kicad_pcb, 68000sbc_v1.kicad_pcb, 68000sbc_v2.kicad_pcb]
2026-06-20 Add English BOM.md for the PGA-68 build; link it from README
    Generated from the actual footprints in the current v2 board
    (68000sbc.kicad_pcb): full purchasing list with packages, quantities,
    IC sockets, the 4-layer PCB spec, and build notes (oscillator
    12 MHz-vs-RC10 caveat, J4 2.00 mm pitch, U3 supplied by the builder).
    Includes a layout-verification summary (netlist identical to the DIP
    board; PGA grid matches datasheet Fig 11-2; DRC 0 unconnected / 0 copper).
2026-06-20 Update PGA68/4層佈線完成報告.md: v2 is now the default board
    Add a 2026-06-20 section: v2 (68000sbc.kicad_pcb) is the finalized
    board (1964 tracks / 96 vias), the full pin-mapping verification chain
    (datasheet Fig 11-2 grid-by-grid), the v2 DRC result (0 unconnected /
    0 copper; 14 non-electrical), and a link to the English BOM.md.
